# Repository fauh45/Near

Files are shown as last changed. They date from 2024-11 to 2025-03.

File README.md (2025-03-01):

# Near

Near is a connected IoT project for couples, friends, and more. It's an exploration on how a simple device could connect people together.

## v1 (MOOD LIGHT)

Version 1 of the Near project is pretty simple, an interconnected small RGB LED mood light device that can trigger the other mood light.
The idea currently is to be simply put on a desk or places where people spend their day most of the time, thus they can receive a simple
notification through the light from other people in the interconnected network of the device.

An exploration of usage of this device could also lead for it to be able to be triggered from external event, or some kind of time-based
event that's important to one or all the device in the interconnected network of it. The concept stays simple, while each other might not
be there, the notification, or "nag" that they receive hopefully make them feel more together.

### Technicality

It's a super simple device. Consisting of ESP32-C3 Super Mini as the MCU, a button, 4 addressable RGB, and 2 capacitors. All of it are mounted on
a small (25 x 28mm) PCB board. All of it mounted on a SMD mounting.

### Timeline

- 27 November 2024, finalized the design, and start the PCB and parts order
- 1 March 2025, two device have been built, firmware nearing beta phase

## Credits

H❤️F Engineering, 2025.

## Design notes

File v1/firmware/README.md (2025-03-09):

# v1 Firmware

The current functionality of v1 is only as such.

1. Onboard the user to connect their WiFi to the device through BLE (or optionally Serial), then ask the user to set their network id
2. Send and receive "nag"s from other device from the same network id
3. Able to update their device through WebSerial

## Ideas

For the WiFi onboarding we could use [Improv WiFI](https://improv-wifi.com). While the device update through WebSerial, we could use [ESP Web Tools](https://esphome.github.io/esp-web-tools/).

While the overall infrastructure for the "nag"s could be defined pretty easily.

```text
Device <-> MQTT <-> Other Device
```

To make sure that each device only connected to the network they want, they could just append their network id on the event name.

## Progress for Beta

- [x] Implement Improv WiFi through BLE
  - [x] Setup GAP & GATT broadcast
  - [x] Setup RPC to handle WiFi connection
  - [x] Add custom RPC to setup network id
- [x] Setup MQTT connection
  - [x] Handle connection to the server
  - [x] Handle button press to send event
  - [x] Handle LED on event listen
- [ ] Fix RMT issue for LED driver not being accurate

## Progress for v1

- [ ] Setup reset system
- [ ] Other improvement we could find on beta?

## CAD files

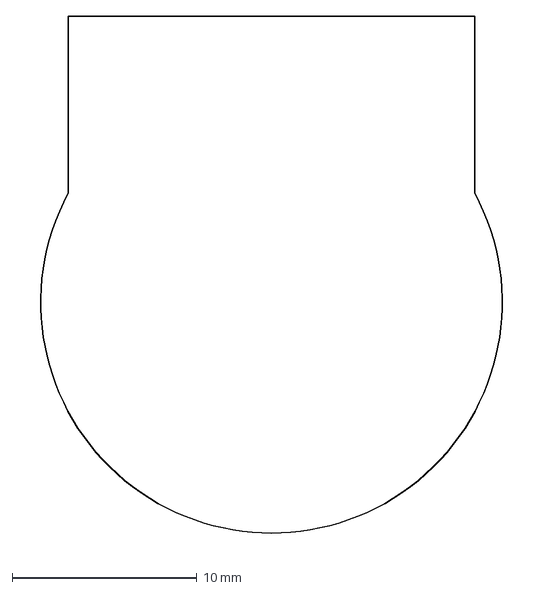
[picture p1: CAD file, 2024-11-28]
v1/pcb_outline.dxf
27.7 x 28.9 mm

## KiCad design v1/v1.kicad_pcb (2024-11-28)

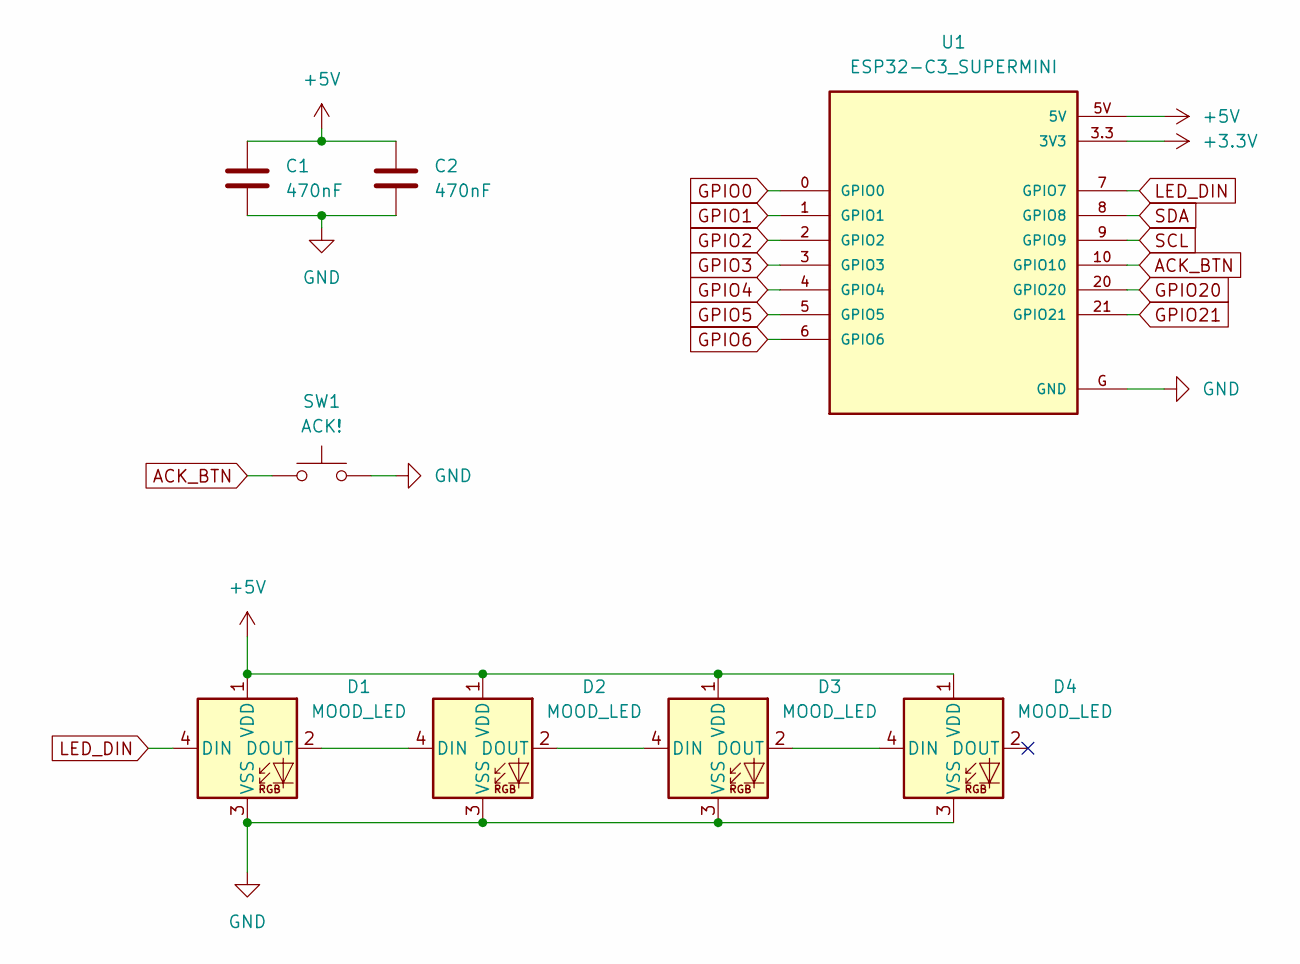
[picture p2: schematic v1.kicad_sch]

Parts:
C1, C2: 470nF; C_0805_2012Metric_Pad1.18x1.45mm_HandSolder
D1, D2, D3, D4: MOOD_LED; LED_WS2812B_PLCC4_5.0x5.0mm_P3.2mm
SW1: ACK!; SW_SPST_Omron_B3FS-100xP
U1: ESP32-C3_SUPERMINI; MODULE_ESP32-C3_SUPERMINI

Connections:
+3.3V: U1.3.3 (3V3)
+5V: C1.1, C2.1, D1.1 (VDD), D2.1 (VDD), D3.1 (VDD), D4.1 (VDD), U1.5V
ACK_BTN: SW1.1, U1.10 (GPIO10)
GND: C1.2, C2.2, D1.3 (VSS), D2.3 (VSS), D3.3 (VSS), D4.3 (VSS), SW1.2, U1.G (GND)
GPIO0: U1.0 (GPIO0)
GPIO1: U1.1 (GPIO1)
GPIO2: U1.2 (GPIO2)
GPIO3: U1.3 (GPIO3)
GPIO4: U1.4 (GPIO4)
GPIO5: U1.5 (GPIO5)
GPIO6: U1.6 (GPIO6)
GPIO20: U1.20 (GPIO20)
GPIO21: U1.21 (GPIO21)
LED_DIN: D1.4 (DIN), U1.7 (GPIO7)
unnamed: D1.2 (DOUT), D2.4 (DIN)
unnamed: D2.2 (DOUT), D3.4 (DIN)
unnamed: D3.2 (DOUT), D4.4 (DIN)
SCL: U1.9 (GPIO9)
SDA: U1.8 (GPIO8)

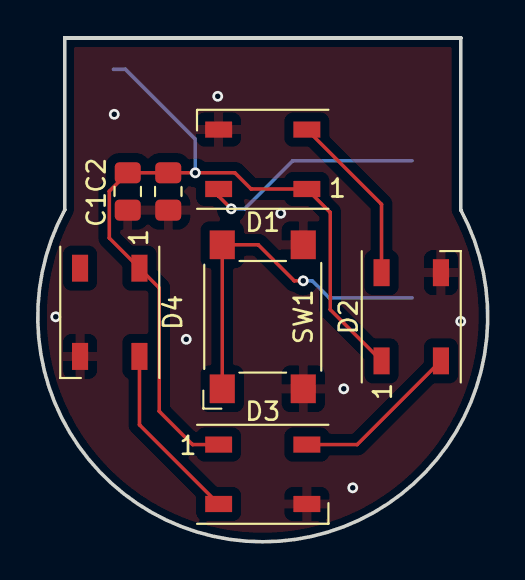
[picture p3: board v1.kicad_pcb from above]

Board: 2 copper layers, 25.0 x 28.0 mm, 8 parts (1 on the bottom side), 7 nets.

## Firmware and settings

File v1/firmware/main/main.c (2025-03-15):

#include "esp_bt.h"
#include "esp_err.h"
#include "esp_event.h"
#include "esp_event_base.h"
#include "esp_log.h"

#include <inttypes.h>
#include <stdbool.h>
#include <stddef.h>
#include <stdint.h>
#include <stdio.h>
#include <stdlib.h>
#include <string.h>
#include <sys/_intsup.h>
#include <sys/_types.h>
#include <sys/types.h>

#include "freertos/FreeRTOSConfig_arch.h"
#include "freertos/idf_additions.h"
#include "led_strip.h"
#include "led_strip_rmt.h"
#include "led_strip_types.h"
#include "nvs_flash.h"

#include "freertos/event_groups.h"
#include "freertos/projdefs.h"
#include "freertos/task.h"

#include "esp_bt_defs.h"
#include "esp_bt_main.h"
#include "esp_gap_ble_api.h"
#include "esp_gatt_common_api.h"
#include "esp_gatt_defs.h"
#include "esp_gatts_api.h"

#include "esp_netif_types.h"
#include "esp_wifi.h"
#include "esp_wifi_default.h"
#include "esp_wifi_types.h"

#include "mbedtls/base64.h"

#include "mqtt_client.h"

#include "portmacro.h"

#include "button_gpio.h"
#include "button_types.h"
#include "iot_button.h"

#include "improv.h"

#include "sdkconfig.h"
#include "soc/clk_tree_defs.h"

#define NEAR_TAG "Near"
#define WIFI_TAG "WiFi"
#define MQTT_TAG "Mqtt"

#define NEAR_DEVICE_NAME "Near v1"

#define NEAR_V1_MQTT_BROADCAST_TOPIC "/near/v1/broadcast/#"
#define NEAR_V1_MQTT_PUBLISH_BROADCAST_TOPIC "/near/v1/broadcast/click"
#define NEAR_V1_MQTT_BROADCAST_QOS 0

#define LED_NUM 4

#define PREPARE_BUF_MAX_SIZE 1024

#define IMPROV_APP_ID 0
#define IMPROV_WIFI_SERVICE_DATA_LEN 6
// How many characteristics does the Improv WiFi have
#define IMPROV_WIFI_CHAR_LEN 5

#define IMPROV_WIFI_GATTS_HANDLE_LEN 20

#define MAX_WIFI_RETRY 3

// Included mqtt host PEM for host verification
extern const uint8_t mqtt_host_pem_start[] asm("_binary_mqtt_host_pem_start");
extern const uint8_t mqtt_host_pem_end[] asm("_binary_mqtt_host_pem_end");

// FreeRTOS event group to signal when WiFi are connected
static EventGroupHandle_t s_wifi_event_group;

// Bits for FreeRTOS event group for the WiFi
#define WIFI_CONNECTED_BIT BIT0
#define WIFI_FAIL_BIT BIT1

// MQTT client intialized on the start
static esp_mqtt_client_handle_t mqtt_client;

// Multipurpose LED state management, used differently for different function
// Set to 0 if state changed!
u_int8_t current_led_state = 0;

// Temporary message store for LED handler
char *temp_message = NULL;
size_t temp_message_len = 0;

led_strip_handle_t led_strip;

// Counter to check how many times the WiFi tried to connect but failed
// This variable is only used if the IMPROV_STATE is not equal to PROVISIONED
// otherwise, the device will keep on trying to connect
static int wifi_retry_num = 0;

// Prepare buffer to hold multiple write packets
typedef struct {
  // Buffer data
  uint8_t *prepare_buf;
  // Current offset
  int prepare_len;
} prepare_buf_type_t;

// Prepare buffer for RPC write, that could be multiple packets long
static prepare_buf_type_t rpc_prepare_write_env;

// Flag to indicate which configuration have been done or not
// <- LSB ------------------------------------------------------ MSB ->
// adv_data_config, scan_rsp_config, none, none, none, none, none, none
static uint8_t config_flags = 0;
#define adv_config_flag (1 << 0)
#define scan_rsp_config_flag (1 << 1)

// Service data as required on BT LE advertisement for Improv WiFi
// https://www.improv-wifi.com/ble/ (Service Data format)
//
// <- LSB ----------------------------------------------------- MSB ->
// current state, capabilities, reserved, reserved, reserved, reserved
//
// TODO: might not be correct, an existing example from the ESP Home team
// (https://github.com/esphome/esphome/blob/30477c764d9353381ef6e8bf186bae703cffbc7f/esphome/components/esp32_improv/esp32_improv_component.cpp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)
// Also need to figure out how to cycle advertising data, as the standard points
// out: "If the device cannot fit all of its advertising data in 31 bytes, it
// should cycle between advertising data."
static uint8_t improv_wifi_service_data[IMPROV_WIFI_SERVICE_DATA_LEN] = {
    IMPROV_STATE_AUTHORIZED, 0x0, 0x0, 0x0, 0x0, 0x0};

#define IMPROV_STATE improv_wifi_service_data[0]
#define IMPROV_CAPABILITIES improv_wifi_service_data[1]

// Current Improv WiFi error state
static uint8_t improv_wifi_curr_error_state = IMPROV_ERR_NO_ERROR;

// GATT Profile representation, contains the identification, connection, etc
struct gatts_profile_inst {
  // Interface type from the registration event
  uint16_t gatts_if;
  uint16_t app_id;
  uint16_t conn_id;
  uint16_t service_handle;
  // GATTS service identifier representation
  esp_gatt_srvc_id_t service_id;
};

// Characteristics callback type
typedef void (*char_cb_t)(esp_gatts_cb_event_t event,
                          esp_ble_gatts_cb_param_t *param);

// GATT Characteristics representation
struct gatts_char_inst {
  // Characteristics callback on READ | WRITE, depends on the property & perm
  char_cb_t char_cb;
  uint16_t char_handle;
  esp_bt_uuid_t char_uuid;
  esp_gatt_perm_t perm;
  esp_gatt_char_prop_t property;
  uint16_t descr_handle;
  esp_bt_uuid_t descr_uuid;
};

// Equal to "00467768-6228-2272-4663-277478268000"
// (Improv WiFi GATTS Service UUID)
static uint8_t improv_wifi_svc_adv_uuid128[ESP_UUID_LEN_128] = {
    0x00, 0x80, 0x26, 0x78, 0x74, 0x27, 0x63, 0x46,
    0x72, 0x22, 0x28, 0x62, 0x68, 0x77, 0x46, 0x00};

// Store the GATT data as we initialize the profile, do connection, etc
static struct gatts_profile_inst improv_gatts_data = {
    .gatts_if = ESP_GATT_IF_NONE,
    .service_id = {.is_primary = true,
                   .id = {.inst_id = 0x00,
                          // Equal to "00467768-6228-2272-4663-277478268000"
                          // (Improv WiFi GATTS Service UUID)
                          .uuid = {.len = ESP_UUID_LEN_128,
                                   .uuid.uuid128 = {0x00, 0x80, 0x26, 0x78,
                                                    0x74, 0x27, 0x63, 0x46,
                                                    0x72, 0x22, 0x28, 0x62,
                                                    0x68, 0x77, 0x46, 0x00}}}},
};

// Definition for RPC handler after long write event
void handle_rpc(uint16_t conn_id);

// Handle capabilities characteristics read event
static void capabilities_char_cb(esp_gatts_cb_event_t event,
                                 esp_ble_gatts_cb_param_t *param) {
  // The response that we're going to send of the read event
  esp_gatt_rsp_t rsp;
  // Set the response to all zero to initialize it
  memset(&rsp, 0, sizeof(esp_gatt_rsp_t));

  rsp.handle = param->read.handle;
  rsp.attr_value.len = 1;
  rsp.attr_value.value[0] = IMPROV_CAPABILITIES;

  // Respond to the read request
  //
  // TODO: if we have more than one service, the gatts if might need to change
  esp_ble_gatts_send_response(improv_gatts_data.gatts_if, param->read.conn_id,
                              param->read.trans_id, ESP_GATT_OK, &rsp);
}

// Handle current state characteristics read event
static void current_state_char_cb(esp_gatts_cb_event_t event,
                                  esp_ble_gatts_cb_param_t *param) {
  // The response that we're going to send of the read event
  esp_gatt_rsp_t rsp;
  // Set the response to all zero to initialize it
  memset(&rsp, 0, sizeof(esp_gatt_rsp_t));

  rsp.handle = param->read.handle;
  rsp.attr_value.len = 1;
  rsp.attr_value.value[0] = IMPROV_STATE;

  // Respond to the read request
  //
  // TODO: if we have more than one service, the gatts if might need to change
  esp_ble_gatts_send_response(improv_gatts_data.gatts_if, param->read.conn_id,
                              param->read.trans_id, ESP_GATT_OK, &rsp);
}

// Handle current error state characteristics read event
static void error_state_char_cb(esp_gatts_cb_event_t event,
                                esp_ble_gatts_cb_param_t *param) {
  // The response that we're going to send of the read event
  esp_gatt_rsp_t rsp;
  // Set the response to all zero to initialize it
  memset(&rsp, 0, sizeof(esp_gatt_rsp_t));

  rsp.handle = param->read.handle;
  rsp.attr_value.len = 1;
  rsp.attr_value.value[0] = improv_wifi_curr_error_state;

  // Respond to the read request
  //
  // TODO: if we have more than one service, the gatts if might need to change
  esp_ble_gatts_send_response(improv_gatts_data.gatts_if, param->read.conn_id,
                              param->read.trans_id, ESP_GATT_OK, &rsp);
}

// Handle RPC command write event
static void rpc_command_char_cb(esp_gatts_cb_event_t event,
                                esp_ble_gatts_cb_param_t *param) {
  esp_gatt_status_t status = ESP_GATT_OK;

  switch (event) {
  case ESP_GATTS_WRITE_EVT: {
    ESP_LOGI(NEAR_TAG, "RPC_COMMAND, value len %d, value :", param->write.len);
    ESP_LOG_BUFFER_HEX(NEAR_TAG, param->write.value, param->write.len);

    // Initialize the buffer if it has not been used before
    if (status == ESP_GATT_OK && rpc_prepare_write_env.prepare_buf == NULL) {
      rpc_prepare_write_env.prepare_buf =
          (uint8_t *)malloc(PREPARE_BUF_MAX_SIZE * sizeof(uint8_t));
      rpc_prepare_write_env.prepare_len = 0;

      // If the buffer is NULL, the malloc have failed, could means there's
      // no more resource in memory
      if (rpc_prepare_write_env.prepare_buf == NULL) {
        ESP_LOGE(NEAR_TAG, "Gatt server prep no mem");
        status = ESP_GATT_NO_RESOURCES;
      }
    }

    // Handle write (non-long) under >23 bytes
    if (!param->write.is_prep) {
      // Copy the while value to buffer for RPC preparation
      memcpy(rpc_prepare_write_env.prepare_buf, param->write.value,
             param->write.len);
      // Add the whole data length
      rpc_prepare_write_env.prepare_len = param->write.len;

      handle_rpc(param->write.conn_id);

      // Free memory after use
      free(rpc_prepare_write_env.prepare_buf);
      rpc_prepare_write_env.prepare_buf = NULL;
      rpc_prepare_write_env.prepare_len = 0;

      // Short write could need response, but not always
      if (param->write.need_rsp)
        esp_ble_gatts_send_response(improv_gatts_data.gatts_if,
                                    param->read.conn_id, param->read.trans_id,
                                    status, NULL);
    }
    // Handle long prep that requires multiple packets
    else {
      // Check if the write offset is bigger than the maximum buffer length
      if (param->write.offset > PREPARE_BUF_MAX_SIZE) {
        status = ESP_GATT_INVALID_OFFSET;
      } else if ((param->write.offset + param->write.len) >
                 PREPARE_BUF_MAX_SIZE) {
        status = ESP_GATT_INVALID_ATTR_LEN;
      }

      // Create temporary response response, each time the long write prep
      // packets arrived, it needs to repond with an ack
      esp_gatt_rsp_t *gatt_rsp =
          (esp_gatt_rsp_t *)malloc(sizeof(esp_gatt_rsp_t));
      if (gatt_rsp) {
        gatt_rsp->attr_value.len = param->write.len;
        gatt_rsp->attr_value.handle = param->write.handle;
        gatt_rsp->attr_value.offset = param->write.offset;
        gatt_rsp->attr_value.auth_req = ESP_GATT_AUTH_REQ_NONE;

        memcpy(gatt_rsp->attr_value.value, param->write.value,
               param->write.len);
        esp_err_t response_status = esp_ble_gatts_send_response(
            improv_gatts_data.gatts_if, param->write.conn_id,
            param->write.conn_id, status, gatt_rsp);

        if (response_status != ESP_OK) {
          ESP_LOGE(NEAR_TAG, "Send long write response failed\n");
        }
        free(gatt_rsp);
      } else {
        ESP_LOGE(NEAR_TAG,
                 "malloc failed, no resource to send response error\n");
        status = ESP_GATT_NO_RESOURCES;
      }

      // Ignore writing to buffer if the process status is not OK
      if (status != ESP_GATT_OK) {
        return;
      }

      // Copy the value using the offset provided
      memcpy(rpc_prepare_write_env.prepare_buf + param->write.offset,
             param->write.value, param->write.len);
      // Add the offset to the buffer to know the total length
      rpc_prepare_write_env.prepare_len += param->write.len;
    }

    break;
  }

  case ESP_GATTS_EXEC_WRITE_EVT: {
    // Write exec could result in two different confirmation, either confirm or
    // cancel it
    //
    // This will handle the confirmation by executing the RPC
    if (param->exec_write.exec_write_flag == ESP_GATT_PREP_WRITE_EXEC) {
      ESP_LOG_BUFFER_HEX(NEAR_TAG, rpc_prepare_write_env.prepare_buf,
                         rpc_prepare_write_env.prepare_len);

      handle_rpc(param->exec_write.conn_id);
    } else {
      // This handle the cancellation of the prep write (long write)
      ESP_LOGI(NEAR_TAG, "ESP_GATT_PREP_WRITE_CANCEL");
    }

    // If the buffer is not empty, free up the buffer for the next call
    if (rpc_prepare_write_env.prepare_buf) {
      free(rpc_prepare_write_env.prepare_buf);
      rpc_prepare_write_env.prepare_buf = NULL;
    }

    // Reset the buffer lenght to zero
    rpc_prepare_write_env.prepare_len = 0;

    break;
  }

  default:
    break;
  }
}
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
void app_main(void) {
  printf("Hello world!\n");

  // Init FreeRTOS event group for the WiFi events
  s_wifi_event_group = xEventGroupCreate();

  // Temporary variable to see the error response of the function
  esp_err_t res;

  // Inititalize the NVS (non-volatile storage)
  // https://docs.espressif.com/projects/esp-idf/en/v5.3.1/esp32/api-reference/storage/nvs_flash.html
  res = nvs_flash_init();

  // Check if the NVS have no free space, or there's a newer version, we can
  // safely remove it and retry.
  //
  // NOTE: Might make the BT/WiFI credentials broken? Although we probably
  // have namespaces, so it won't be too full? Might be broken after flash
  // though, if the size(new) > size(old)
  if (res == ESP_ERR_NVS_NO_FREE_PAGES ||
      res == ESP_ERR_NVS_NEW_VERSION_FOUND) {
    ESP_ERROR_CHECK(nvs_flash_erase());
    res = nvs_flash_init();
  }
  ESP_ERROR_CHECK(res);

  /* Start button initialization */
  button_config_t ack_btn_config = {0};
  button_gpio_config_t ack_btn_gpio_config = {
      .gpio_num = 10, .active_level = 0, .enable_power_save = true};
  button_handle_t ack_btn_handler_inst;
  ESP_ERROR_CHECK(iot_button_new_gpio_device(
      &ack_btn_config, &ack_btn_gpio_config, &ack_btn_handler_inst));
  // TODO: add more button events here
  iot_button_register_cb(ack_btn_handler_inst, BUTTON_SINGLE_CLICK, NULL,
                         ack_btn_handler, NULL);

  /* Start BT Initialization */

  // Clear up controller data used by Classic Bluetooth controller, as we
  // will only use BLE.
  // https://docs.espressif.com/projects/esp-idf/en/v5.3.1/esp32/api-reference/bluetooth/controller_vhci.html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
  ESP_ERROR_CHECK(esp_bt_controller_mem_release(ESP_BT_MODE_CLASSIC_BT));

  // Helpful walkthrough on BT and GATT initialization
  // https://github.com/espressif/esp-idf/blob/v5.3.1/examples/bluetooth/bluedroid/ble/gatt_server/tutorial/Gatt_Server_Example_Walkthrough.md

  // Bluetooth controller configuration, mostly configurable from menuconfig
  // https://docs.espressif.com/projects/esp-idf/en/v5.3.1/esp32/api-reference/bluetooth/controller_vhci.html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
  esp_bt_controller_config_t bt_cfg = BT_CONTROLLER_INIT_CONFIG_DEFAULT();
  // Try to initialize the bluetooth controller
  res = esp_bt_controller_init(&bt_cfg);
  if (res) {
    ESP_LOGE(NEAR_TAG, "%s init controller failed: %s", __func__,
             esp_err_to_name(res));
    return;
  }

  // Try to enable the bluetooth controller
  res = esp_bt_controller_enable(ESP_BT_MODE_BLE);
  if (res) {
    ESP_LOGE(NEAR_TAG, "%s enable bluetooth failed: %s", __func__,
             esp_err_to_name(res));
    return;
  }

  // Initialize and allocate resources for Bluetooth
  // https://docs.espressif.com/projects/esp-idf/en/v5.3.1/esp32/api-reference/bluetooth/esp_bt_main.html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
  res = esp_bluedroid_init();
  if (res) {
    ESP_LOGE(NEAR_TAG, "%s init bluedroind failed: %s", __func__,
             esp_err_to_name(res));

    return;
  }

  // Try to enable bluedroid resources for bluetooth
  res = esp_bluedroid_enable();
  if (res) {
    ESP_LOGE(NEAR_TAG, "%s enable bluedroind failed: %s", __func__,
             esp_err_to_name(res));

    return;
  }

  res = esp_ble_gatts_register_callback(gatts_event_handler);
  if (res) {
    ESP_LOGE(NEAR_TAG, "%s gatts register error: %s", __func__,
             esp_err_to_name(res));

    return;
  }

  res = esp_ble_gap_register_callback(gap_event_handler);
  if (res) {
    ESP_LOGE(NEAR_TAG, "%s gap register error: %s", __func__,
             esp_err_to_name(res));

    return;
  }

  /* Start WiFi Initialization */

  ESP_ERROR_CHECK(esp_netif_init());

  ESP_ERROR_CHECK(esp_event_loop_create_default());
  esp_netif_create_default_wifi_sta();

  wifi_init_config_t wifi_init_config = WIFI_INIT_CONFIG_DEFAULT();
  ESP_ERROR_CHECK(esp_wifi_init(&wifi_init_config));

  // Event Loop Handler for WiFi related events
  esp_event_handler_instance_t wifi_event_handler_inst;
  esp_event_handler_instance_t ip_event_handler_inst;

  // Register the WiFi event handler for the required events
  ESP_ERROR_CHECK(esp_event_handler_instance_register(
      WIFI_EVENT, WIFI_EVENT_STA_DISCONNECTED, &wifi_event_handler, NULL,
      &wifi_event_handler_inst));
  ESP_ERROR_CHECK(esp_event_handler_instance_register(
      IP_EVENT, IP_EVENT_STA_GOT_IP, &wifi_event_handler, NULL,
      &ip_event_handler_inst));

  // Set the WiFi to station mode to connect to other APs
  ESP_ERROR_CHECK(esp_wifi_set_mode(WIFI_MODE_STA));
  // Start the WiFi station
  ESP_ERROR_CHECK(esp_wifi_start());

  // Handle WiFi configuration if there's already something on the NVS
  wifi_config_t wifi_config;
  res = esp_wifi_get_config(WIFI_IF_STA, &wifi_config);

  /* Start the LED task */
  led_strip_config_t strip_config = {.strip_gpio_num = 7,
                                     .max_leds = LED_NUM,
                                     .led_model = LED_MODEL_WS2812,
                                     .color_component_format =
                                         LED_STRIP_COLOR_COMPONENT_FMT_GRB,
                                     .flags = {.invert_out = false}};

  led_strip_rmt_config_t rmt_config = {.clk_src = RMT_CLK_SRC_DEFAULT,
                                       .resolution_hz = 40 * 1000 * 1000,
                                       .mem_block_symbols = 192,
                                       .flags = {
                                           .with_dma = false,
                                       }};

  ESP_ERROR_CHECK(
      led_strip_new_rmt_device(&strip_config, &rmt_config, &led_strip));

  xTaskCreate(led_light_task, "LED_light_task", configMINIMAL_STACK_SIZE, NULL,
              1, NULL);

  /* Start MQTT Initialization */

  const esp_mqtt_client_config_t mqtt_cfg = {
      .broker.address.uri = CONFIG_MQTT_HOSTNAME,
      .broker.verification.certificate = (const char *)mqtt_host_pem_start,
      // TODO: add the chip id with custom prefix
  };
  mqtt_client = esp_mqtt_client_init(&mqtt_cfg);
  esp_mqtt_client_register_event(mqtt_client, ESP_EVENT_ANY_ID,
                                 mqtt_event_handler, NULL);

  /* Start WiFi NVS reconnection strategy */
  size_t ssid_len = strlen((char *)wifi_config.sta.ssid);

  ESP_LOGI(WIFI_TAG, "SSID length on the NVS %d", ssid_len);

  // If there's already a wifi configuration, check if at least the SSID is
  // not empty
  if (res == ESP_OK && ssid_len != 0) {
    IMPROV_STATE = IMPROV_STATE_PROVISIONING;
    res = esp_wifi_connect();

    ESP_LOGI(WIFI_TAG, "Error code for wifi_connect on init %d", res);

    // Ignore if the WiFi connect doesn't work
    if (res == ESP_OK) {
      // Wait until the WiFi connected or some error occured after max retry
      EventBits_t wifi_status = xEventGroupWaitBits(
          s_wifi_event_group, WIFI_CONNECTED_BIT | WIFI_FAIL_BIT, pdFALSE,
          pdFALSE, portMAX_DELAY);

      ESP_LOGI(WIFI_TAG, "wifi status after trying to connect using nvs %s",
               wifi_status & WIFI_FAIL_BIT ? "fail!" : "success!");

      // There's some error!
      if (wifi_status & WIFI_FAIL_BIT) {
        IMPROV_STATE = IMPROV_STATE_AUTHORIZED;
        improv_wifi_curr_error_state = IMPROV_ERR_UNABLE_TO_CONN;

        xEventGroupClearBits(s_wifi_event_group, WIFI_FAIL_BIT);
        current_led_state = 0;
      } else {
        // Success!
        IMPROV_STATE = IMPROV_STATE_PROVISIONED;
        improv_wifi_curr_error_state = IMPROV_ERR_NO_ERROR;

        esp_mqtt_client_start(mqtt_client);
        current_led_state = 0;
      }
    }
    // If somehow the esp_wifi_connect fails, set it back to authorized mode
    else {
      IMPROV_STATE = IMPROV_STATE_AUTHORIZED;
      current_led_state = 0;
    }
  }

  /* Start BT GAP App registeration */

  res = esp_ble_gatts_app_register(IMPROV_APP_ID);
  if (res) {
    ESP_LOGE(NEAR_TAG, "%s gatt app register error: %s", __func__,
             esp_err_to_name(res));

    return;
  }

  res = esp_ble_gatt_set_local_mtu(500);
  if (res) {
    ESP_LOGE(NEAR_TAG, "%s gatt set mtu error: %s", __func__,
             esp_err_to_name(res));

    return;
  }

  // TODO: set security, etc
  // https://github.com/espressif/esp-idf/blob/v5.3.1/examples/bluetooth/bluedroid/ble/gatt_server_service_table/tutorial/Gatt_Server_Service_Table_Example_Walkthrough.md
}

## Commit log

2024-11-28 feat: v1 near
    [pcb_outline.dxf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]
2024-11-30 chore: set the target to be ESP32-C3
2024-12-02 docs: service data might not be correct
    [main.c]
2024-12-14 feat: add notify on new error state
    [main.c]
2024-12-14 fix: ssid and password not initialized
    [main.c]
2024-12-15 fix: without response packet not handled
    [main.c]
2024-12-15 fix: string print, test state change
    [main.c]
2025-02-11 feat: add wifi initialization
    also fix IMPROV_CAPABILITIES to bit 1 instead of 0
    [main.c]
2025-03-09 feat: initial ws2812b driver
2025-03-09 feat: handle provisioning and errors with leds
    [main.c]
2025-03-09 fix: somewhat fixed the rmt timing
    [main.c]
2025-03-10 fix: better result somehow
    [main.c]
2025-03-15 fix: reduce status led even more
    [main.c]
